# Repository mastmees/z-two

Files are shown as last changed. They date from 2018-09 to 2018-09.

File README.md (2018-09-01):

# z-two
CP/M machine with Z80 emulated on ATMega

See project page at http://www.nomad.ee/micros/z-two/ for full story.

Z-Two runs about 110000 Z80 instructions per second on emulator
running on ATMega1284p, and is fully functional CP/M machine,
albeit a slow one. It uses SD card as storage (maxed out disk
space for CP/M, 16x8MB drives), VGA monitor (80x30 text)
and PS/2 keyboard. There is a serial port with USB-Serial
converter for getting data in and out of the machine.

The emulation code can also be built to run emulated version of
the machine on linux or OSX where the SD card is emulated on a
regular file.

Z80 emulation code was written from scratch, and has features for
debugging and profiling the emulator. It runs all documented Z80
instructions, and enough undocumented ones to pass all 
Frank Cringle's yaze tests (documented flags only).

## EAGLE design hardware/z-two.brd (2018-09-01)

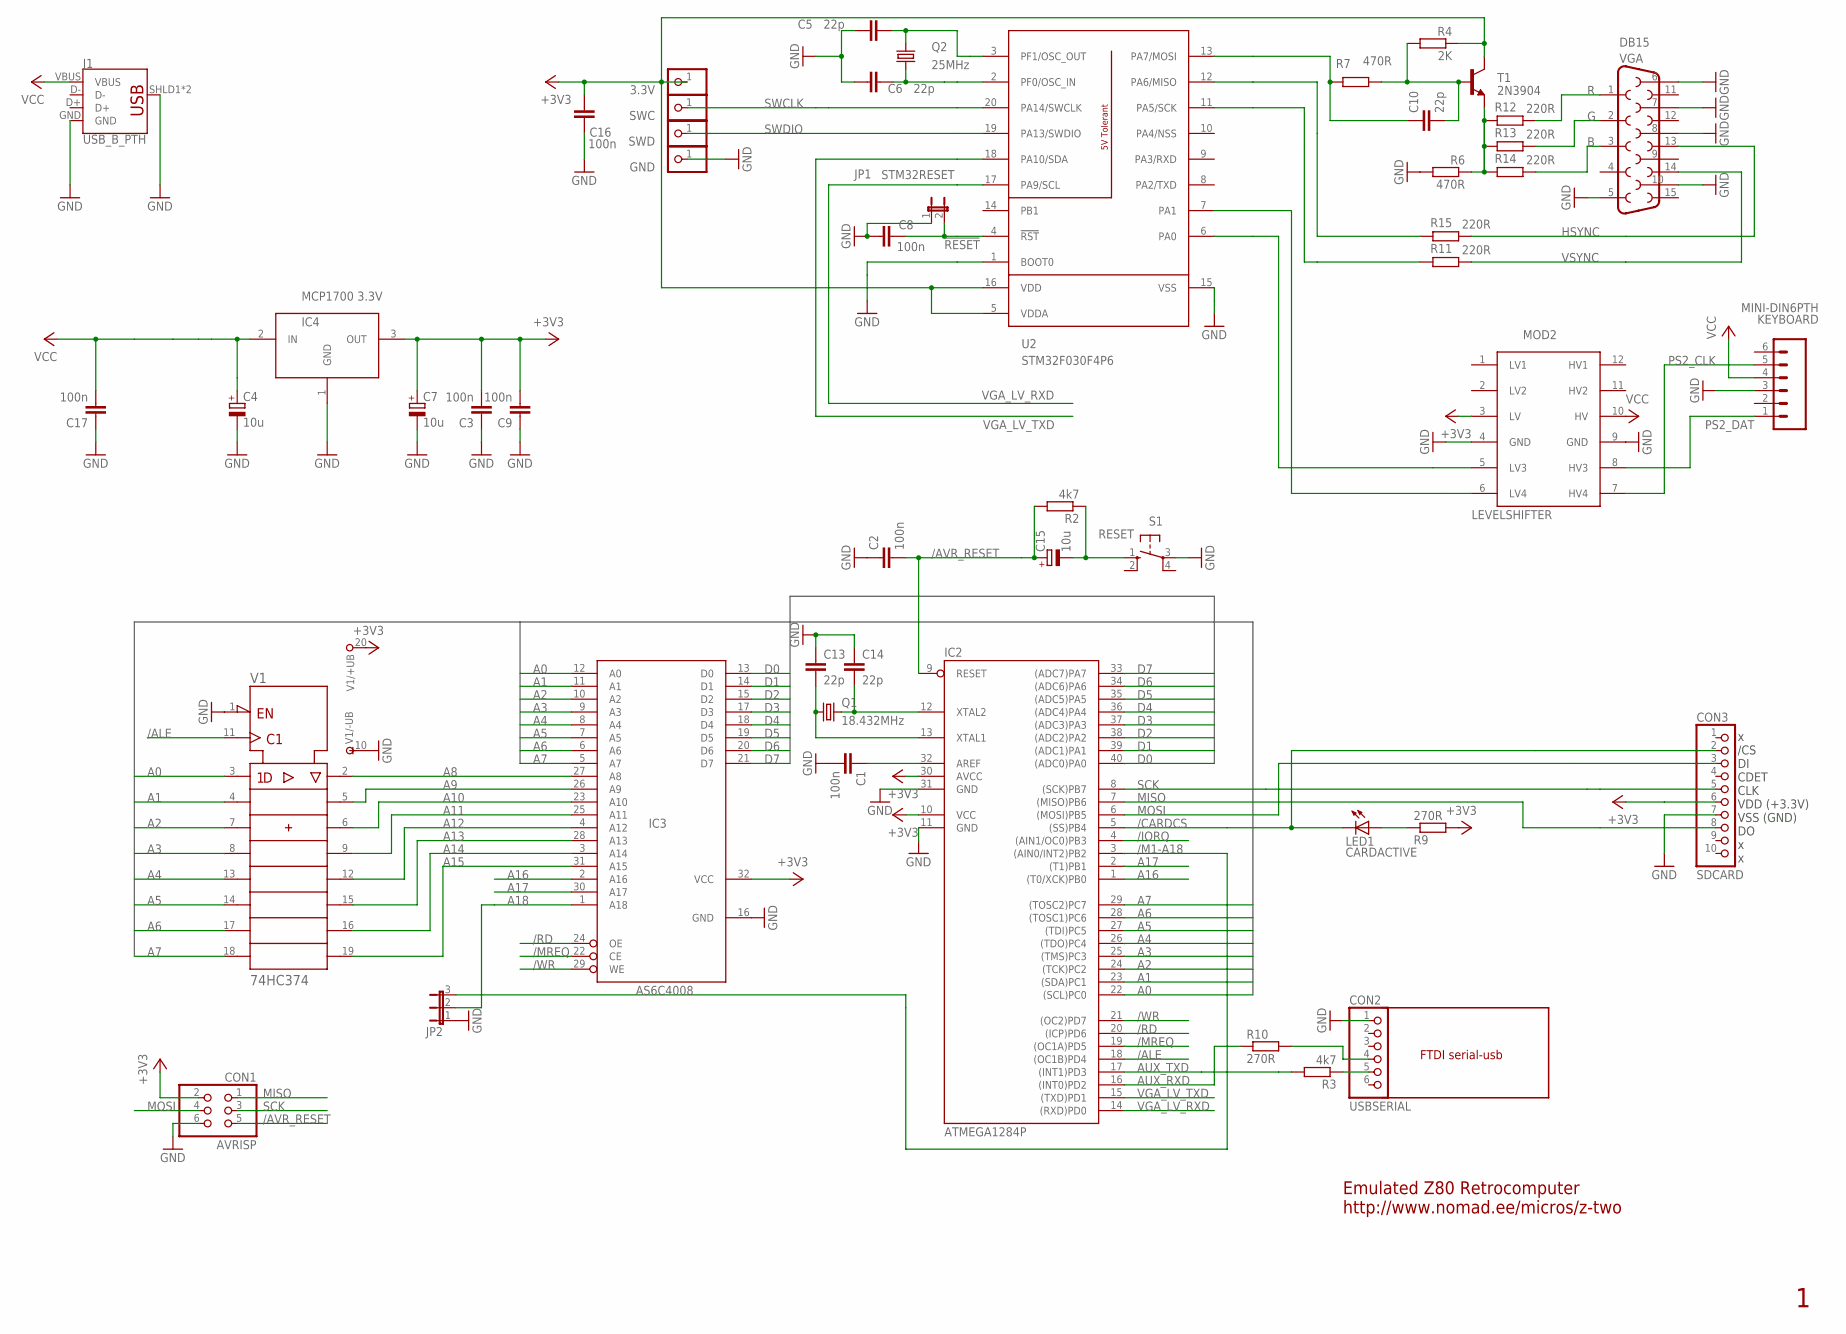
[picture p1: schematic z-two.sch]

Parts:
3.3V: PINHD-1X1; 1X01
C1, C2, C3, C8, C9, C16, C17: 100n; C025-025X050; PARTNO 0.1UF, 0603
C4, C7, C15: 10u; E2,5-5
C5, C6, C10: 22p; C025-025X050; PARTNO 22PF, 0603
C13, C14: 22p; C025-025X050; PARTNO 0.1UF, 0603
CON1: AVRISP; 2X03
CON2: USBSERIAL; 1X06
CON3: SDCARD; 1X10
GND: PINHD-1X1; 1X01
IC2: ATMEGA1284P; DIL40
IC3: AS6C4008; DIP32
IC4: MCP1700 3.3V; TO-92
J1: USB_B_PTH; USB-B-PTH
JP1: STM32RESET; 1X02
JP2: JP2E; JP2
KEYBOARD: MINI-DIN6PTH; MINI-DIN6
LED1: CARDACTIVE; LED3MM
MOD2: LEVELSHIFTER; LAVELSHIFTER_N
Q1: 18.432MHz; HC49/S
Q2: 25MHz; HC49/S
R2, R3: 4k7; 0204/7
R4: 2K; 0204/7; PARTNO 2K, 0603
R6, R7: 470R; 0204/7; PARTNO 475R, 0603
R9: 270R; 0204/7; PARTNO 475R, 0603
R10: 270R; 0204/7
R11, R12, R13, R14, R15: 220R; 0204/7
S1: RESET; B3F-10XX
SWC: PINHD-1X1; 1X01
SWD: PINHD-1X1; 1X01
T1: 2N3904; TO92
U2: STM32F030F4P6; MISC-PROCESSOR_TSSOP20
V1: 74HC374; DIL20
VGA: DB15

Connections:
25MHZ: C5.2, Q2.2, U2.3 (PF1/OSC_OUT)
!RESET: C8.1, JP1.2, U2.4 (!RST)
+3V3: 3.3V.1, C3.2, C7.+, C9.2, C16.1, CON1.2, CON3.6, IC2.10 (VCC), IC2.30 (AVCC), IC3.32 (VCC), IC4.3 (OUT), MOD2.3 (LV), R4.1, R9.2, T1.1 (C), U2.5 (VDDA), U2.16 (VDD), V1.20 (+UB)
/ALE: IC2.18 ((OC1B)PD4), V1.11 (CLK)
/AVR_RESET: C2.2, C15.+, CON1.5, IC2.9 (RESET), R2.2
/CARDCS: CON3.2, IC2.5 ((SS)PB4), LED1.K (C)
/IORQ: IC2.4 ((AIN1/OC0)PB3)
/M1-A18: IC2.3 ((AIN0/INT2)PB2), JP2.3
/MREQ: IC2.19 ((OC1A)PD5), IC3.22 (CE)
/RD: IC2.20 ((ICP)PD6), IC3.24 (OE)
/WR: IC2.21 ((OC2)PD7), IC3.29 (WE)
A0: IC2.22 ((SCL)PC0), IC3.12 (A0), V1.3 (1D)
A1: IC2.23 ((SDA)PC1), IC3.11 (A1), V1.4 (2D)
A2: IC2.24 ((TCK)PC2), IC3.10 (A2), V1.7 (3D)
A3: IC2.25 ((TMS)PC3), IC3.9 (A3), V1.8 (4D)
A4: IC2.26 ((TDO)PC4), IC3.8 (A4), V1.13 (5D)
A5: IC2.27 ((TDI)PC5), IC3.7 (A5), V1.14 (6D)
A6: IC2.28 ((TOSC1)PC6), IC3.6 (A6), V1.17 (7D)
A7: IC2.29 ((TOSC2)PC7), IC3.5 (A7), V1.18 (8D)
A8: IC3.27 (A8), V1.2 (1Q)
A9: IC3.26 (A9), V1.5 (2Q)
A10: IC3.23 (A10), V1.6 (3Q)
A11: IC3.25 (A11), V1.9 (4Q)
A12: IC3.4 (A12), V1.12 (5Q)
A13: IC3.28 (A13), V1.15 (6Q)
A14: IC3.3 (A14), V1.16 (7Q)
A15: IC3.31 (A15), V1.19 (8Q)
A16: IC2.1 ((T0/XCK)PB0), IC3.2 (A16)
A17: IC2.2 ((T1)PB1), IC3.30 (A17)
A18: IC3.1 (A18), JP2.2
AUX_RXD: IC2.16 ((INT0)PD2), R10.1
AUX_TXD: IC2.17 ((INT1)PD3), R3.2
B: R14.1, VGA.3
D0: IC2.40 ((ADC0)PA0), IC3.13 (D0)
D1: IC2.39 ((ADC1)PA1), IC3.14 (D1)
D2: IC2.38 ((ADC2)PA2), IC3.15 (D2)
D3: IC2.37 ((ADC3)PA3), IC3.17 (D3)
D4: IC2.36 ((ADC4)PA4), IC3.18 (D4)
D5: IC2.35 ((ADC5)PA5), IC3.19 (D5)
D6: IC2.34 ((ADC6)PA6), IC3.20 (D6)
D7: IC2.33 ((ADC7)PA7), IC3.21 (D7)
G: R13.1, VGA.2
GND: C1.2, C2.1, C3.1, C4.-, C5.1, C6.1, C7.-, C8.2, C9.1, C13.1, C14.1, C16.2, C17.1, CON1.6, CON2.1, CON3.7, GND.1, IC2.11 (GND), IC2.31 (GND), IC3.16 (GND), IC4.1 (GND), J1.GND, J1.SHLD1 (SHIELD), J1.SHLD2 (SHIELD), JP1.1, JP2.1, KEYBOARD.3, MOD2.4 (GND), MOD2.9 (GND), R6.2, S1.3, U2.1 (BOOT0), U2.15 (VSS), V1.1 (!OC), V1.10 (-UB), VGA.5, VGA.6, VGA.7, VGA.8, VGA.10
HSYNC: R15.1, VGA.13
MISO: CON1.1, CON3.8, IC2.7 ((MISO)PB6)
MOSI: CON1.4, CON3.3, IC2.6 ((MOSI)PB5)
unnamed: C6.2, Q2.1, U2.2 (PF0/OSC_IN)
unnamed: R15.2, U2.12 (PA6/MISO)
unnamed: R6.1, R12.2, R13.2, R14.2, T1.3 (E)
unnamed: C14.2, IC2.12 (XTAL2), Q1.2
unnamed: C1.1, IC2.32 (AREF)
unnamed: R11.2, U2.11 (PA5/SCK)
unnamed: MOD2.6 (LV4), U2.7 (PA1)
unnamed: MOD2.5 (LV3), U2.6 (PA0)
unnamed: C10.2, R4.2, R7.1, T1.2 (B)
unnamed: C10.1, R7.2, U2.13 (PA7/MOSI)
unnamed: CON2.5, R3.1
unnamed: C13.2, IC2.13 (XTAL1), Q1.1
unnamed: CON2.4, R10.2
unnamed: C15.-, R2.1, S1.1 (S)
unnamed: LED1.A, R9.1
PS2_CLK: KEYBOARD.5, MOD2.7 (HV4)
PS2_DAT: KEYBOARD.1, MOD2.8 (HV3)
R: R12.1, VGA.1
SCK: CON1.3, CON3.5, IC2.8 ((SCK)PB7)
SWCLK: SWC.1, U2.20 (PA14/SWCLK)
SWDIO: SWD.1, U2.19 (PA13/SWDIO)
VCC: C4.+, C17.2, IC4.2 (IN), J1.VBUS, KEYBOARD.4, MOD2.10 (HV)
VGA_LV_RXD: IC2.14 ((RXD)PD0), U2.17 (PA9/SCL)
VGA_LV_TXD: IC2.15 ((TXD)PD1), U2.18 (PA10/SDA)
VSYNC: R11.1, VGA.14

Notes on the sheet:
FTDI serial-usb
x /CS DI CDET CLK VDD (+3.3V) VSS (GND) DO x x
Emulated Z80 Retrocomputer http://www.nomad.ee/micros/z-two

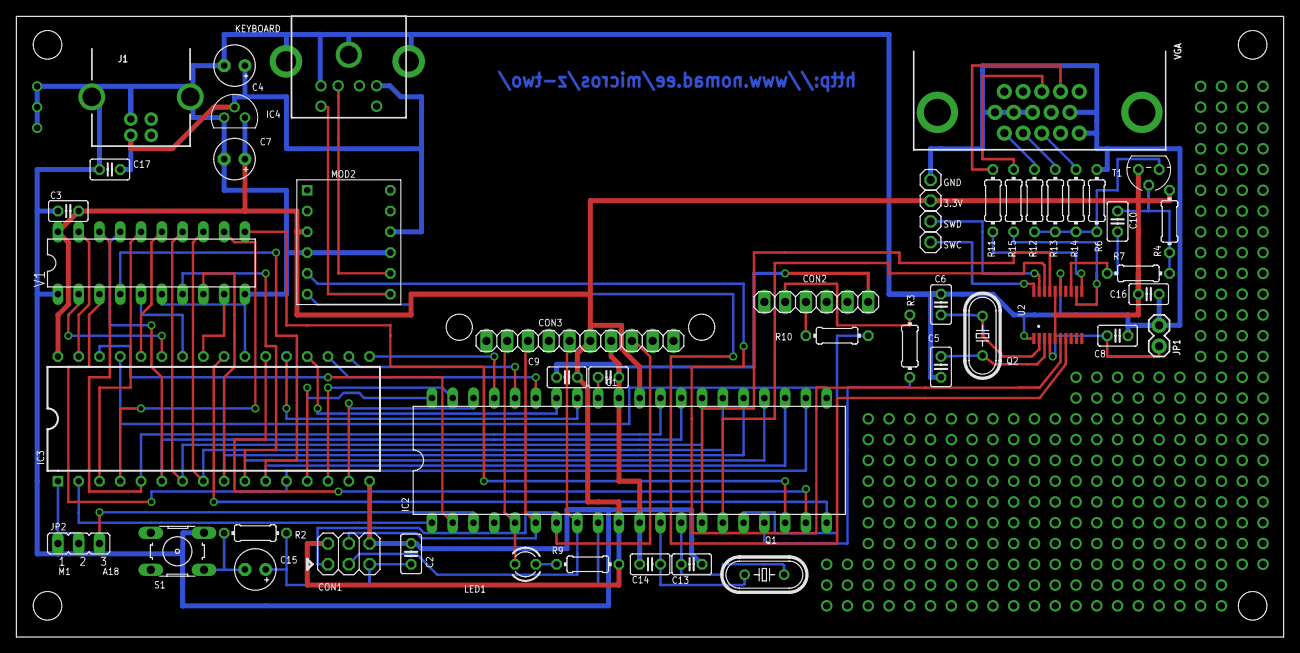
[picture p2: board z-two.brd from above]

Board: 2 copper layers, 154.9 x 75.9 mm, 50 parts (0 on the bottom side), 70 nets.

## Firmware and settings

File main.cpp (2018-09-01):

/* The MIT License (MIT)
 
  Copyright (c) 2018 Madis Kaal <mast@nomad.ee>
 
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
  THE SOFTWARE IS PROVIDED "AS IS", WITHOUT WARRANTY OF ANY KIND, EXPRESS OR
  IMPLIED, INCLUDING BUT NOT LIMITED TO THE WARRANTIES OF MERCHANTABILITY,
  FITNESS FOR A PARTICULAR PURPOSE AND NONINFRINGEMENT. IN NO EVENT SHALL THE
  AUTHORS OR COPYRIGHT HOLDERS BE LIABLE FOR ANY CLAIM, DAMAGES OR OTHER
  LIABILITY, WHETHER IN AN ACTION OF CONTRACT, TORT OR OTHERWISE, ARISING FROM,
  OUT OF OR IN CONNECTION WITH THE SOFTWARE OR THE USE OR OTHER DEALINGS IN THE
  SOFTWARE.
*/


#include <avr/io.h>
#include <avr/interrupt.h>
#include <avr/sleep.h>
#include <avr/wdt.h>
#include <string.h>
#include <avr/pgmspace.h>
#include <util/delay.h>

#include "z80.hpp"
#include "console.hpp"
#include "machine.hpp"
#include "sdcard.hpp"
#include "partitioner.hpp"
#include "aux.hpp"
#include "sdcard.hpp"

SDCard sdcard;
z80 cpu;

ISR(WDT_vect)
{
}

/*
I/O configuration
-----------------
I/O pin                               direction    DDR  PORT
PA0 D0                                input        0    1
PA1 D1                                input        0    1
PA2 D2                                input        0    1
PA3 D3                                input        0    1
PA4 D4                                input        0    1
PA5 D5                                input        0    1
PA6 D6                                input        0    1
PA7 D7                                input        0    1

PB0 A16                               output       1    0
PB1 A17                               output       1    0
PB2 A18                               output       1    0
PB3 /IORQ                             output       1    1
PB4 /SS                               output       1    1
PB5 MOSI                              output       1    1
PB6 MISO                              input        0    1
PB7 SCK                               output       1    1

PC0 A0                                output       1    0
PC1 A1                                output       1    0
PC2 A2                                output       1    0
PC3 A3                                output       1    0
PC4 A4                                output       1    0
PC5 A5                                output       1    0
PC6 A6                                output       1    0
PC7 A7                                output       1    0

PD0 RxD0                              input        0    1
PD1 TxD0                              output       1    1
PD2 RxD1                              input        0    1
PD3 TxD1                              output       1    1
PD4 /ALE                              output       1    1
PD5 /MREQ                             output       1    1
PD6 /RD                               output       1    1
PD7 /WR                               output       1    1
*/
int main(void)
{
  MCUSR=0;
  MCUCR=(1<<JTD); // this does not actually seem to help, fuse needs to be blown too

  // I/O directions and initial state
  DDRA=0x00;
  PORTA=0xff;
  DDRB=0xbf;
  PORTB=0xf8;
  DDRC=0xff;
  PORTC=0x00;
  DDRD=0xfa;
  PORTD=0xff;
  //
  set_sleep_mode(SLEEP_MODE_IDLE);
  sleep_enable();
  // configure watchdog to interrupt&reset, 4 sec timeout
  WDTCSR|=0x18;
  WDTCSR=0xe8;
  // configure timer2 for generic timekeeping, triggering
  // overflow interrupts every 10ms
  TCCR2A=0;
  TCCR2B=7;
  TCNT2=255-180;
  TIMSK2=1;
  sei();
  console.init();
  aux.init();
  console.print("\ec\x0f\e[H\e[2JZ80 emulator for AVR 1.0\r\n");
  sdcard.Init();
  checkdisk();
  copy_bootloader();
  cpu.reset();
  while (1) {
    cpu.step(10000); // running z80 instructions in batches reduces overhead
    wdt_reset();
    WDTCSR|=0x40;
  } 
}

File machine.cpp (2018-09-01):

/* The MIT License (MIT)
 
  Copyright (c) 2018 Madis Kaal <mast@nomad.ee>
 
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
  THE SOFTWARE IS PROVIDED "AS IS", WITHOUT WARRANTY OF ANY KIND, EXPRESS OR
  IMPLIED, INCLUDING BUT NOT LIMITED TO THE WARRANTIES OF MERCHANTABILITY,
  FITNESS FOR A PARTICULAR PURPOSE AND NONINFRINGEMENT. IN NO EVENT SHALL THE
  AUTHORS OR COPYRIGHT HOLDERS BE LIABLE FOR ANY CLAIM, DAMAGES OR OTHER
  LIABILITY, WHETHER IN AN ACTION OF CONTRACT, TORT OR OTHERWISE, ARISING FROM,
  OUT OF OR IN CONNECTION WITH THE SOFTWARE OR THE USE OR OTHER DEALINGS IN THE
  SOFTWARE.
*/
#include "machine.hpp"
#include "sdcard.hpp"

/*
this module implements the physical machine around z80 emulator, providing access
to RAM and I/O space, and implementing some of the I/O using AVR hardware - 
serial ports, SD card inteface, and timer.
*/


enum MSTATE { IDLE, BIOS, CPM, TIMECOUNTER };

static uint32_t timecounter,timecountersnapshot; // counts 10ms ticks
static uint8_t auxbaud;
static uint8_t sd0,sd1,sd2,sd3,sds;
static uint8_t sdc;
static uint16_t dataofs;
static MSTATE state;
static uint16_t count;

static uint16_t baudrates[8]= {
 50, 300,1200,2400,4800,9600,19200,38400 
};

// prototypes for functions that handle internal I/O space access
static uint8_t io_read(uint16_t adr);
static void io_write(uint16_t adr,uint8_t b);

ISR(TIMER2_OVF_vect)
{
  TCNT2=255-180;
  timecounter++;
  console.tick();
}

#define mreq_low() PORTD&=0xdf
#define mreq_high() PORTD|=0x20
#define wr_low() PORTD&=0x7f
#define wr_high() PORTD|=0x80
#define ale_low() PORTD&=0xef
#define ale_high() PORTD|=0x10
#define rd_low() PORTD&=0xbf
#define rd_high() PORTD|=0x40
#define iorq_low() PORTB&=0xf7
#define iorq_high() PORTB|=0x08

// read one byte of data from memory address
// Z80 only directly addresses 64K, any paging method for larger RAM
// needs to be applied here
uint8_t z80::readram(uint16_t adr)
{
uint8_t b;
  PORTC=adr>>8;
  ale_low();
  ale_high();
  PORTC=adr&255;
  mreq_low();
  rd_low();
  PORTA=0xff; // have to delay one instruction here, so do something useful and enable pullups
  b=PINA;
  rd_high();
  mreq_high();
  return b; 
}

// write one byte of data to memory address
// Z80 only directly addresses 64K, any paging method for larger RAM
// needs to be applied here
void z80::writeram(uint16_t adr,uint8_t data)
{
  PORTC=adr>>8;
  ale_low();
  ale_high();
  PORTC=adr&255;
  DDRA=0xff;
  PORTA=data;
  mreq_low();
  wr_low();
  wr_high();
  mreq_high();
  DDRA=0x00;
}

// read data from I/O space.
// real Z80 actually sets the high 8 bits of address, but
// current emulator only uses low 8
uint8_t z80::readio(uint16_t adr)
{
uint8_t b;
  if (adr>=0xa0)
    b=io_read(adr);
  else {
    PORTC=adr>>8;
    ale_low();
    ale_high();
    PORTC=adr&255;
    iorq_low();
    rd_low();
    PORTA=0xff;
    b=PINA;
    rd_high();
    iorq_high();
  }
  return b; 
}

// write data to I/O space.
// real Z80 actually sets the high 8 bits of address, but
// current emulator only uses low 8
void z80::writeio(uint16_t adr,uint8_t data)
{ 
  if (adr>=0xa0)
    io_write(adr,data);
  else {
    PORTC=adr>>8;
    ale_low();
    ale_high();
    PORTC=adr&255;
    DDRA=0xff;
    PORTA=data;
    iorq_low();
    wr_low();
    wr_high();
    iorq_high();
    DDRA=0;
  }
}

// this is called when invalid instruction is encountered
void z80::fault(void)
{
  console.print("\r\nZ80 emulator fault. PC=");
  console.phex(pcreg>>8);
  console.phex(pcreg&255);
  while (1); 
}

void copy_bootloader(void)
{
uint16_t a;
uint8_t b;
  console.print("Bootstrapping...\r\n");
  for (a=0;a<sizeof(bootstrap_bin);a++) {
    b=pgm_read_byte(&bootstrap_bin[a]);
    cpu.writeram(a,b);
  }  
}


static uint8_t io_read(uint16_t adr)
{
uint8_t b=0;
  switch (adr) {

    // misc operations data read
    
    case 0xa1: 

      switch (state) {
        case BIOS: // reading bios code
          if (count>=sizeof(monitor_bin))
            b=0x55;
          else {
            b=pgm_read_byte(&monitor_bin[count]);
            count++;
          }
          break;
        case CPM:
          if (count>=sizeof(cpm_bin))
            b=0x55;
          else {
            b=pgm_read_byte(&cpm_bin[count]);
            count++;
          }
          break;
        case TIMECOUNTER:
          b=timecountersnapshot&255;
          timecountersnapshot>>=8;
          break;
        default:
          state=IDLE;
          break;
      }
      break;

    // console input / status
    
    case 0xa2: // console data
      if (console.rxready()) {
        b=console.receive();
      }
      break;
    case 0xa3: // console status
      b=console.rxready()?1:0;
      b|=console.txfull()?2:0;
      break;
    
    // aux input/status
    
    case 0xa4: // aux data
      b=aux.receive();
      break;
    case 0xa5: // aux status
      b|=aux.rxcount()?0x40:0;
      b|=aux.txcount()?0x20:0;
      b|=aux.txfull()?0x10:0;
      b|=auxbaud;
      break;
      
    // sd card status/read
    
    case 0xa8: // A_SDC - read back SD card command
      b=sdc;
      break;
    case 0xa9: // A_SDD - read SD card data
      if ((sdc&0xc0)==0x80) { // still reading sector data
        b=sdcard.GetBuf()[dataofs];
        dataofs++;
        if (dataofs>511)
          sdc|=0x40;
      }
      break;
    case 0xaa: // A_SDS - read SD card status
      b=sds;
      break;
    case 0xab:
      b=sd0;
      break;
    case 0xac:
      b=sd1;
      break;
    case 0xad:
      b=sd2;
      break;
    case 0xae:
      b=sd3;
      break;
  }
  return b;
}
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

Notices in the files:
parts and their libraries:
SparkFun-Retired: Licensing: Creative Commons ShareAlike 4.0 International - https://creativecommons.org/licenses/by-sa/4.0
